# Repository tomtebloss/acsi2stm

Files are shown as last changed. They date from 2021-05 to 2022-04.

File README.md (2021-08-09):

**EXPERIMENTAL BRANCH - WORK IN PROGRESS**

Known issues on the integrated driver:
 * Mounting/overlay logic needs a full revamp.
 * Need to test the TOS loader correctly.

Known issues on the filesystem engine:
 * Fsfirst/Fsnext don't work well when creating/deleting files: Breaks recursive directory operations.
 * Pexec is not supported: you can't execute programs from the filesystem.
 * File descriptors are lost/reset when rescanning drives.
 * Filesystem access is very slow, code needs a lot of optimizations.

Known issues on the floppy emulator:
 * Low level access is not good. Formatting and low level copy doesn't work.
 * SD card hot swapping does not always work well.

Feature wish list:
 * RTC support (only needs a battery on the STM32).
 * Automatic drive desktop icon installation for TOS < 2.xx.
 * Dynamic floppy image mounting by hooking Pexec (and DESKTOP.INF auto patching).

ACSI2STM: Atari ST ACSI hard drive emulator
===========================================

This code provides a hard drive emulator for your Atari ST using an inexpensive STM32 microcontroller and a SD card.

The aim of this project is to be very easy to build, extremely cheap, reliable and safe for your precious vintage machine.

The module supports up to 5 SD card readers, showing them as 5 different ACSI devices plugged in. You can choose the ACSI
ID of each SD card by soldering CS wires on the matching STM32 pin.

It can work in 4 ways:
 * Expose a raw SD card as a hard disk to the Atari.
 * Expose a hard disk image file to the Atari.
 * Expose floppy disk images to the Atari with a built-in driver.
 * Expose a SD filesystem as a GEMDOS drive on the Atari.

Folders
-------

Here is how the project is organized:

 * acsi2stm: The arduino project.
 * doc: All the documentation about the project.
 * stmdrive: Sources for the floppy emulator and GEMDOS driver.
 * LICENSE: The license for the whole project.

Documentation
-------------

For a quick start guide on how to use an already built unit, check [HowToUse](doc/HowToUse.md).

For information about how to make the hardware, check [Hardware](doc/Hardware.md).

For information about compiling the firmware with Arduino and uploading it to the STM32, check [Compiling](doc/Compiling.md)

The doc folder contains more documentation, you may wish to browse it if needed.

Credits
-------

I would like to thanks the people that put invaluable information online that made this project possible in a finite amount of
time. Without them, this project would have not existed.

 * The http://atari.8bitchip.info website and his author, who also contributes on various forums.
 * The Hatari developpers. I used its source code as a reference for ACSI commands.
 * The emuTOS developpers. I used its source code for many tricks and lists.
 * The UltraSatan project for their documentation.
 * Sr Antonio, Edu Arana, Frederick321, Ulises74, Maciej G., Olivier Gossuin and Marcel Prisi for their very detailed feedback.
   that helped me a lot for fine tuning the DRQ/ACK signals and other various aspects of the projects.
 * All the kind people sharing their issues on GitHub. That really helps a lot making this project better.

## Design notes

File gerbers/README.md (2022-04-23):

<h1 align="center">
PCB for combining bluepill, microSD card reader and DB19 connector
</h1>

---

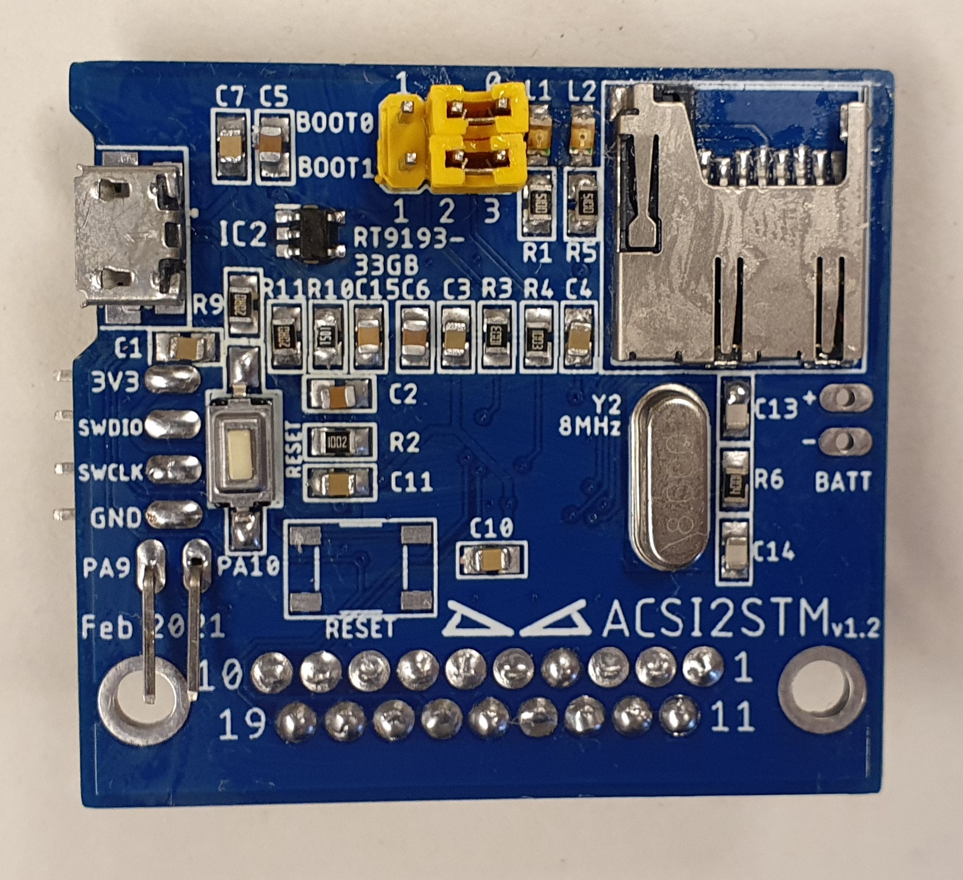
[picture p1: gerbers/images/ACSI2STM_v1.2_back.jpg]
Back side of soldered board
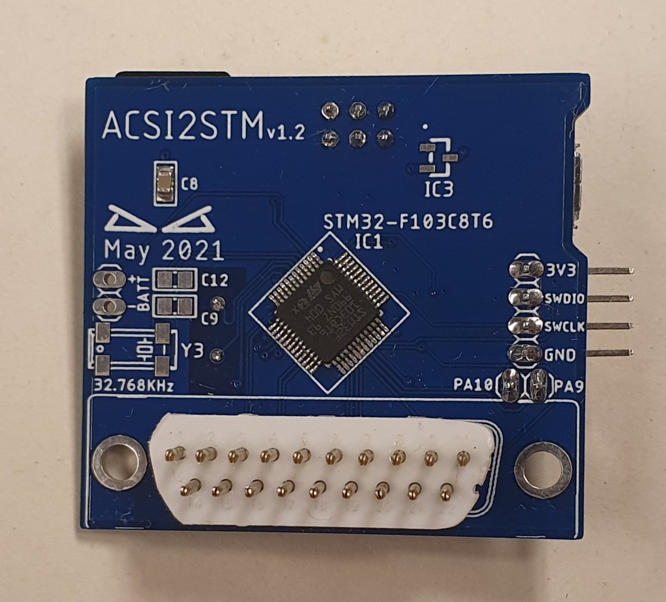
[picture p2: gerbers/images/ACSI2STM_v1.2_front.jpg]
Front side of soldered board


## History

This PCB was only made for me and the goal was to get a small PCB made with everything on it. A few people asked if I could make it public. So it is a "work in progress". There is no way to change ID at the moment, but I have plans to make a new PCB to change ID on the unit between 0-4. Right now the ID is fixed to ID0. There is also some components not needed for this project but was present on the bluepill. So download the zip with the gerbers and order your board from your favourite PCB manufactor. Based on the [bluepill schematics]. 

---

## "bluepill"

<h1 align="center">
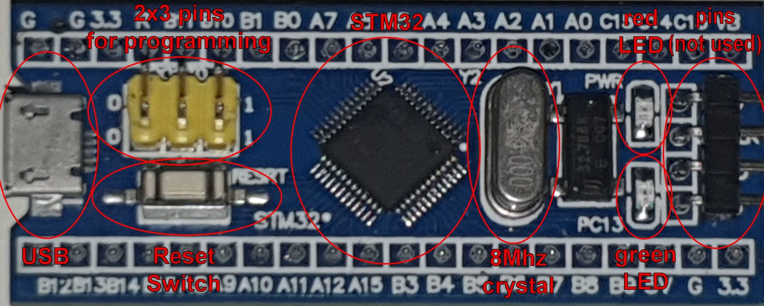
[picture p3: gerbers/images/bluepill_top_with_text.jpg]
Top side of bluepill PCB
 
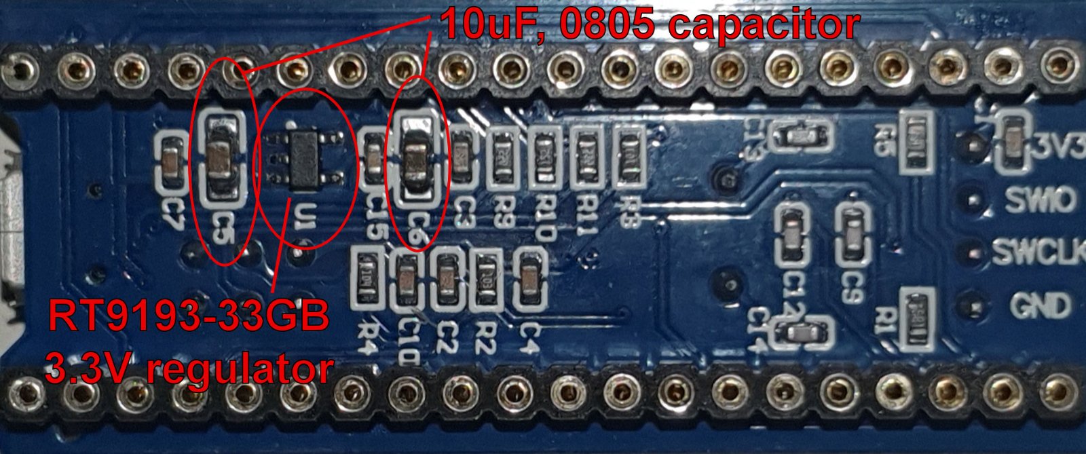
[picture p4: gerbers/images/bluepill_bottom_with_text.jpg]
Bottom side of bluepill PCB
 
</h1>
 
Some parts can be be used from the [bluepill] board. Most of the passive part on the bluepill is 0603 and although they could have been used on the new board, I opted to use 0805 for everything for easier soldering. They are cheap anyway. All components can however be order individually, you don't have to scavange parts from a bluepill. <strong>20220423: [R10 changed to 1.5K]. BOM updated.</strong>

  * USB connector can probably fit on the new board. But you have to cut of the small plastic pegs underneath. I used new connector on mine.
  * 8MHz crystal.
  * 2x3 pinheader (and associated jumper).
  * Red and yellow LED. I used new LED on mine (green for power (L1) and yellow for activity(L2)).
  * Right angle pins. Only used for programming. 
  * Reset switch. There is two different version depending on bluepill model. Only use one on the new board.
  * STM32.
  * LDO 5V to 3.3V regulator.
  * 10uF capacitors.

---

## Useful info

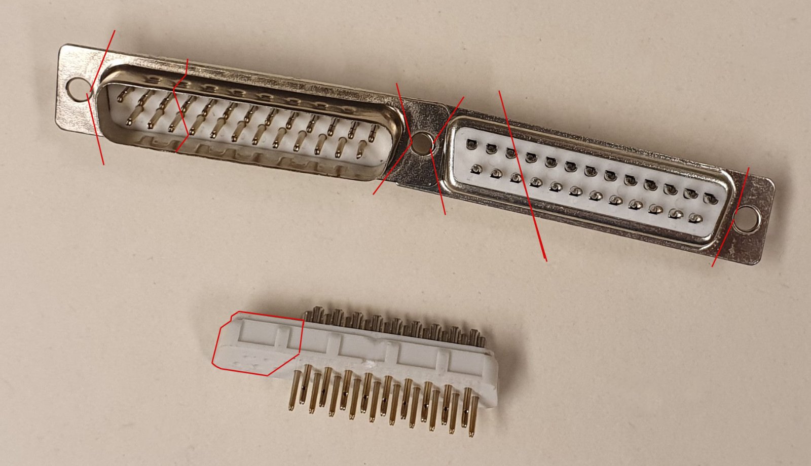
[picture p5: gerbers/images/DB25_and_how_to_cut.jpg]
Cut down a DB25
-  Use only one 3.3V LDO regulator. If you don't use the LDO from the bluepill there is a SOT-23 footprint on the other side (IC3) that can be used. 
- Battery connector, 32,768KHz crystal (Y3), capacitor is not used (C9 and C12).
- For programming the STM32 use the `3V3`, `GND`, `PA9` and `PA10` with a [FTDI programmer] (with 3V3 on VCC pin). Set `BOOT0` to 1 with the jumper. Reset switch is probably of use as well when programming. Download [STM32CubeProgrammer] and upload the v2.1 [binary] firmware to the STM32. <strong>20220103: I updated the [binary] to get it working better as discussed in [issue 16]. I used 18 MHz but also did a version with 8MHz.</strong>
- I made the PCB to use 19 pin D-SUB connector and solder it directly into the PCB. They can be pricy to get hold of so I made my own out of 25 pin D-SUB connector insted. The solder end don't go that far into the PCB so don't force it in and try to get it flush. There should be a gap.
- <strong>20220103: I could never get the unit to autoboot with HDDriver. But EmuTOS detected it and autobooted. Also P.Putniks HD driver autobooted. Tried in TOS v2.06, TOS v1.04 (with [IDE patch] from Christian Zietz) and EmuTOS v1.</strong>

---

## Speed test

I used [AHPT] by P.Putnik to test the units speed. Here you can download [AHPT94.ZIP] directly. <strong>Updated speed test 20220103.</strong>

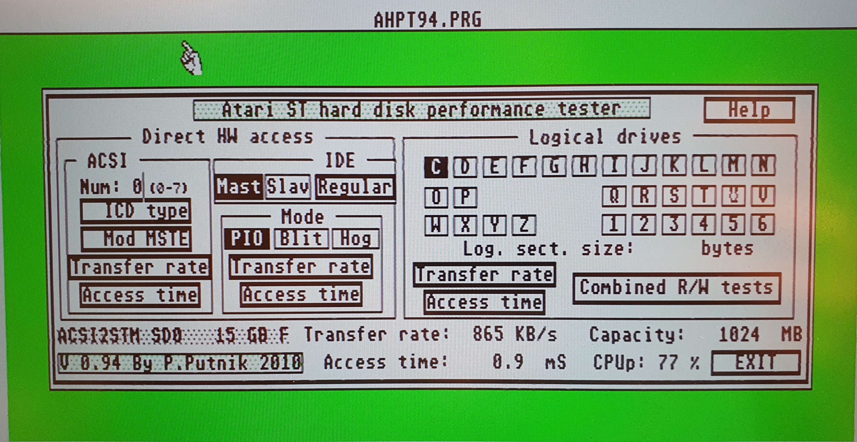
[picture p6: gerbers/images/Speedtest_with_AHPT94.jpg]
Speed test with AHPT94


---

Bill of material for this is listed in the <a href="https://github.com/tomtebloss/acsi2stm/blob/master/gerbers/ACSI2STM%20v1.2%20BOM.txt">`ACSI2STM vx.x BOM.txt`</a> 

PCB made by [DoG] in Eagle v9.6.2.

[bluepill]: https://stm32-base.org/boards/STM32F103C8T6-Blue-Pill.html
[FTDI programmer]: https://www.google.com/search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
[binary]: binary/acsi2stm.v2.1.18MHz.ino.generic_stm32f103c.bin
[STM32CubeProgrammer]: https://www.st.com/en/development-tools/stm32cubeprog.html
[AHPT]: https://atari.8bitchip.info/ahpt.html
[AHPT94.ZIP]: https://atari.8bitchip.info/AHPT9.ZIP
[DoG]: https://www.exxoshost.co.uk/forum/memberlist.php?mode=viewprofile&u=255
[issue 16]: https://github.com/retro16/acsi2stm/issues/16
[IDE patch]: https://github.com/czietz/ideboot
[bluepill schematics]: https://stm32-base.org/assets/pdf/boards/original-schematic-STM32F103C8T6-Blue_Pill.pdf
[R10 changed to 1.5K]: https://stm32-base.org/boards/STM32F103C8T6-Blue-Pill.html

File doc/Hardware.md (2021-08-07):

Building the hardware for ACSI2STM
==================================

Hardware needed
---------------

 * A STM32F103C8T6 or compatible board. You can find them for a few dollars online. The "blue pill" works out of the box
   and the "black pill" requires minor modifications.
 * One or more SD card port(s) for your STM32. You can also solder wires on a SD to microSD adapter.
 * One or more SD card(s).
 * A male DB19 port (you can modify a DB25 port to fit) with a ribbon cable.
 * (recommended) A protoboard PCB to solder all the components and wires together.
 * Do *NOT* connect USB data lines on the STM32. Use the +5V or +3.3V pin to power it if you are unsure.

Building the ACSI cable
-----------------------

ACSI pin numbers, looking at the male connector pins:

    ---------------------------------
    \ 01 02 03 04 05 06 07 08 09 10 /
     \ 11 12 13 14 15 16 17 18 19  /
       ---------------------------

Use this table to match pins on the ACSI port and the STM32:

| ACSI | STM32 | PIN | Description |
|:----:|:-----:|:---:|---|
|  01  | PB8 | D0  | Data 0 (LSB) |
|  02  | PB9 | D1  | Data 1 |
|  03  | PB10  | D2  | Data 2 |
|  04  | PB11  | D3  | Data 3 |
|  05  | PB12  | D4  | Data 4 |
|  06  | PB13  | D5  | Data 5 |
|  07  | PB14  | D6  | Data 6 |
|  08  | PB15  | D7  | Data 7 (MSB) |
|  09  | PB7 | CS  | Chip Select |
|  10  | PA8 | IRQ | Interrupt |
|  11  | GND | GND | Ground |
|  12  | (nc)  | RST | Reset |
|  13  | GND | GND | Ground |
|  14  | PA12  | ACK | Acknowledge |
|  15  | GND | GND | Ground |
|  16  | PB6 | A1  | Address bit |
|  17  | GND | GND | Ground |
|  18  | (nc)  | R/W | Read/Write |
|  19  | PA11  | DRQ | Data request |

**WARNING**: Pinout changed in v2.0: PA8 and PA12 are swapped.

Notes:

 * GND is soldered together on the ST side. You can use a single wire for ground.
 * Reset is not needed as the STM32 resets itself if it stays in an inconsistent state for more than 2 seconds.
 * Keep the wires short. I had strange behavior with cables longer than 10cm (4 inches).
 * The read/write pin is not needed.
 * You can build a DB19 out of a DB25 by cutting 6 pins on one side and part of the external shielding. Male DB25
   are easy to find because they were used for parallel port cables or serial port sockets.
 * You will have to power the STM32 separately (e.g. with a USB cable).

Connecting the SD cards
-----------------------

SD card pins

        ______________________
      /|  |  |  |  |  |  |  | |
     /_|01|02|03|04|05|06|07|8|
    |  |__|__|__|__|__|__|__|_|
    |09|                      |
    |__|                      |

Use this table to match pins on the SD card port and the STM32:

| SD  | STM32 | PIN |
|:---:|:-----:|:---:|
| 01  | PA4 * | CS  |
| 02  | PA7 | MOSI|
| 03  | GND | VSS |
| 04  | +3.3V | VDD |
| 05  | PA5 | CLK |
| 06  | GND | VSS |
| 07  | PA6 | MISO|
| 08  | (nc)  | RSV |
| 09  | (nc)  | RSV |

If you want to use multiple SD cards, connect all SD card pins to the same STM32 pins except CS (SD pin 1).

Here is the table that indicates the STM32 pin for each CS pin of the different SD cards:

| ACSI ID | STM32 | Connect to |
|---:|:---|---|
| 0 | PA4 | SD 0 pin 1 or GND |
| 1 | PA3 | SD 1 pin 1 or GND |
| 2 | PA2 | SD 2 pin 1 or GND |
| 3 | PA1 | SD 3 pin 1 or GND |
| 4 | PA0 | SD 4 pin 1 or GND |

Leave unused CS pins unconnected.

**WARNING**: Pinout changed in v2.0: PA0 was added, PBx were removed and unused SD card CS pins *must not* be grounded anymore.

For example, if you want 3 SD cards detected on ACSI IDs 0, 1 and 4:
 * Connect PA4 to pin 1 of the first SD card.
 * Connect PA3 to pin 1 of the second SD card.
 * Connect PA0 to pin 1 of the third SD card.
 * Leave PA1 and PA2 unconnected.

Notes:

 * The SD card had 2 GND pins. I don't know if they have to be both grounded, maybe one wire is enough.
 * You should put a decoupling capacitor of about 100nF between VDD and VSS, as close as possible from the SD card pins.
 * If you need other ACSI IDs, you can change the sdCs array in the source code. See "Compile-time options" below.
 * CS pins must be on GPIO port A (PA pins).

Using on a "Black pill" STM32 board
-----------------------------------

If you have these cheap "STM32 minimum development boards" from eBay, Amazon, Banggood or other chinese sellers, chances are that
you have either a "blue pill" or a "black pill" board. "blue" or "black" refers to the color of the PCB.

The problem with black pill designs is that the onboard LED is wired on PB12 instead of PC13, messing with data signals.

You will have to desolder the onboard LED (or its current-limiting resistor right under).

If you want an activity LED, put an external one with a 1k resistor in series on PC13.

Other boards were not tested and may require further adjustments.

Adapting a v1.0 board to v2.0
-----------------------------

If you built a board for v1.0, here are the changes you will have to do:

 * Cut the trace (or wire) between pin A8 of the STM32 and pin 14 of the ACSI port
 * Cut the trace (or wire) between pin A12 of the STM32 and pin 10 of the ACSI port
 * Solder a wire between pin A8 of the STM32 and pin 10 of the ACSI port
 * Solder a wire between pin A12 of the STM32 and pin 14 of the ACSI port
 * Cut any traces between A4, A3, A2, A1, B0, B1, B3 of the STM32 that go to GND. Make sure to keep traces that go to the SD card
   CS pin.

Sorry for the major inconvenience, but I had to do this to use hardware timers and the SdFat library that
use fixed pins on the microcontroller.

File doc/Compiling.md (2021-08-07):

Compiling and flashing the software for ACSI2STM
================================================

For a tutorial on how to build the hardware part, see the [Hardware](Hardware.md) page.

Hardware needed
---------------

 * A STM32 board.
 * A USB-serial dongle for programming the STM32 chip, with a 3.3V USART.
 * Do *NOT* connect USB data lines on the STM32. Use the +5V or +3.3V pin to power it if you are unsure.

You may use STLink, but I had no success using it, some other people did, your mileage may vary.

Software needed
---------------

 * The Arduino software with the Roger Clark Melbourne STM32 library.
 * The SdFat Arduino library by Bill Greiman.
 * A hard drive driver for your Atari ST:
   * AHDI should work but is not recommended.
   * ICD pro driver is tested.
   * Peter Putnik's driver is reported to work.

Installing software
-------------------

Install the [STM32 library](https://github.com/rogerclarkmelbourne/Arduino_STM32/wiki/Installation). The doc says that it only
works on Arduino 1.8.5 but that does seems to work with more recent versions too (confirmed working with Arduino 1.18.15).

In the Tools / Manage Libraries menu of the Arduino interface, search for "SdFat" and install "SdFat by Bill Greiman".

In the Tools menu of the Arduino interface, select the following:

 * Board: Generic STM32F103C series
 * Variant: STM32F103C8
 * Upload method: Serial
 * CPU speed: 72MHz (normal)
 * Optimize: Faster (-O2)
 * Port: your USB serial dongle

Note: you can use any setting in the "Optimize" menu. O2 is recommended for fastest performance, O3 does not bring any speed
improvement but generates much bigger code.

If you have different options in the Tools menu, it may be because you don't have the correct board installed.

Then, you will be able to upload the program to the STM32.

Programming the STM32
---------------------

Set the USB dongle to 3.3V if you have a jumper for that. Connect TX to PA10, RX to PA9 and the GND pins together.

On the STM32 itself, set the BOOT0 jumper to 1 to enable the serial flash bootloader. Reset the STM32 then click Upload.

Once the chip is programmed, switch the BOOT0 jumper back to 0.

Note: the debug output sends data at 115200bps. Set the serial monitor accordingly.

Compile-time options
--------------------

The file acsi2stm/acsi2stm.h contains a few #define that you can change. They are described in the source itself.

Settings that you might wish to change:

 * ACSI_DEBUG: Enables debug output on the serial port. Moderate performance penalty.
 * ACSI_VERBOSE: Requires ACSI_DEBUG. Logs all commands and low-level trafic on the serial port. High performance penalty.
 * IMAGE_FILE_NAME: The image file to use as a hard disk image on the SD card.
 * DRIVE_A_FILE_NAME: The image file to use as a floppy disk image. Same for drive B.
 * ACSI_BOOT_OVERLAY: Turn on or off the boot sector overlay to load the integrated driver.

If you need a reference debug output, see the debug_output.txt file. This contains a full trace of a standard ICD PRO setup booting.

Rebuilding the emudrive blob
----------------------------

To build the driver, you need [vasm](http://sun.hasenbraten.de/vasm/).

You need the _m68k_ CPU with the _mot_ syntax. Build it using the following command:

    make CPU=m68k SYNTAX=mot

Once compiled, put vasmm68k_mot anywhere in your PATH.

Generating the release zip package
----------------------------------

The build_relase.sh script is provided. It's a bash script for Linux, but if you use any other platform, you
can run the vasmm68k_mot and xxd commands by hand. If you have a script for other platforms, contributions are welcome.

Note: this script will modify acsi2stm.h to patch ACSI2STM_VERSION from the VERSION file.  It will also regenerate acsi2stm/boot.h with the new driver payload.

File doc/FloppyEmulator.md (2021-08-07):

ACSI2STM floppy emulator
========================

ACSI2STM supports mounting floppy images by hooking block device driver calls. While this is not bullet proof (it will fail for
programs that do direct hardware access) it's a nice convenience to mount *.st files easily.

This driver supports SD card hotplug and falls back to the hardware drive when no SD card is inserted or no image is found.

Floppy images can be up to 32M and must be formatted using FAT12.

How to use
----------

Format your SD card in FAT32 or EXFAT, create a folder named "acsi2stm" and put a floppy image file named "drive_a.st" in it.

You can also put an image named "drive_b.st" to emulate drive B. The driver is smart enough to enable or disable the popup that
asks to insert floppy B in drive A as required.

How not to use
--------------

If you have a hard drive driver that mounts the SD card containing floppy images don't touch the floppy image file while the floppy
drive is being accessed.

Low level tools such as disk formatters/copiers are unlikely to work. Some can be fixed by improving the driver, others cannot be
supported at all because they do direct hardware access.

Supported image formats
-----------------------

The driver only supports raw floppy images (a.k.a. *.st files). The file must be a multiple of 512 bytes or it won't load at all.

The driver will try to guess floppy geometry based on the file size when accessing the image using low level track/side/sector
addressing scheme.

What if I have more than 1 SD card with floppy images ?
-------------------------------------------------------

The driver will try to load images from devices in the reverse order: it tries the last SD card slot first, then goes back to the
first slot until it finds a suitable floppy image.

You can put drive A and drive B images on separate SD card readers.

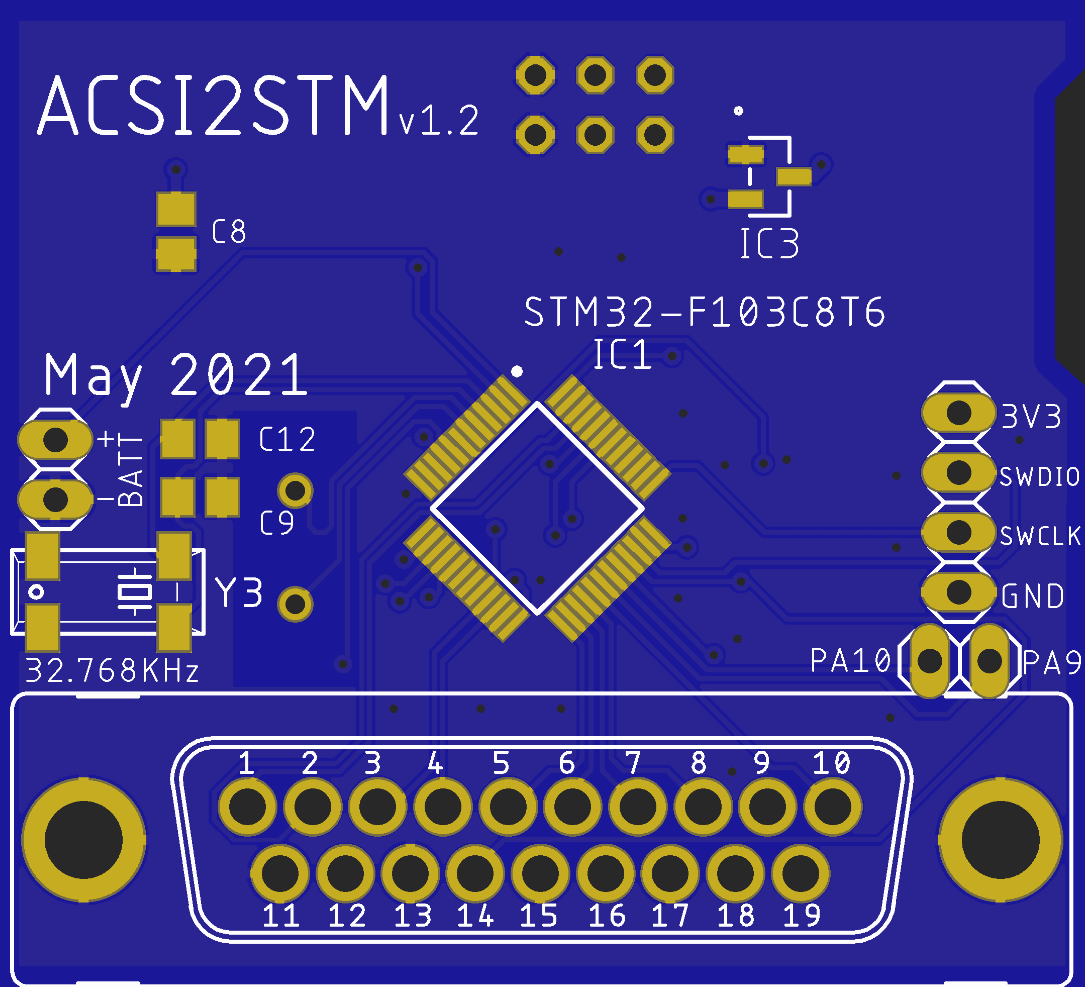
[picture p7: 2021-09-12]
gerbers/images/ACSI2STM_v1.2_PCB_top.gif

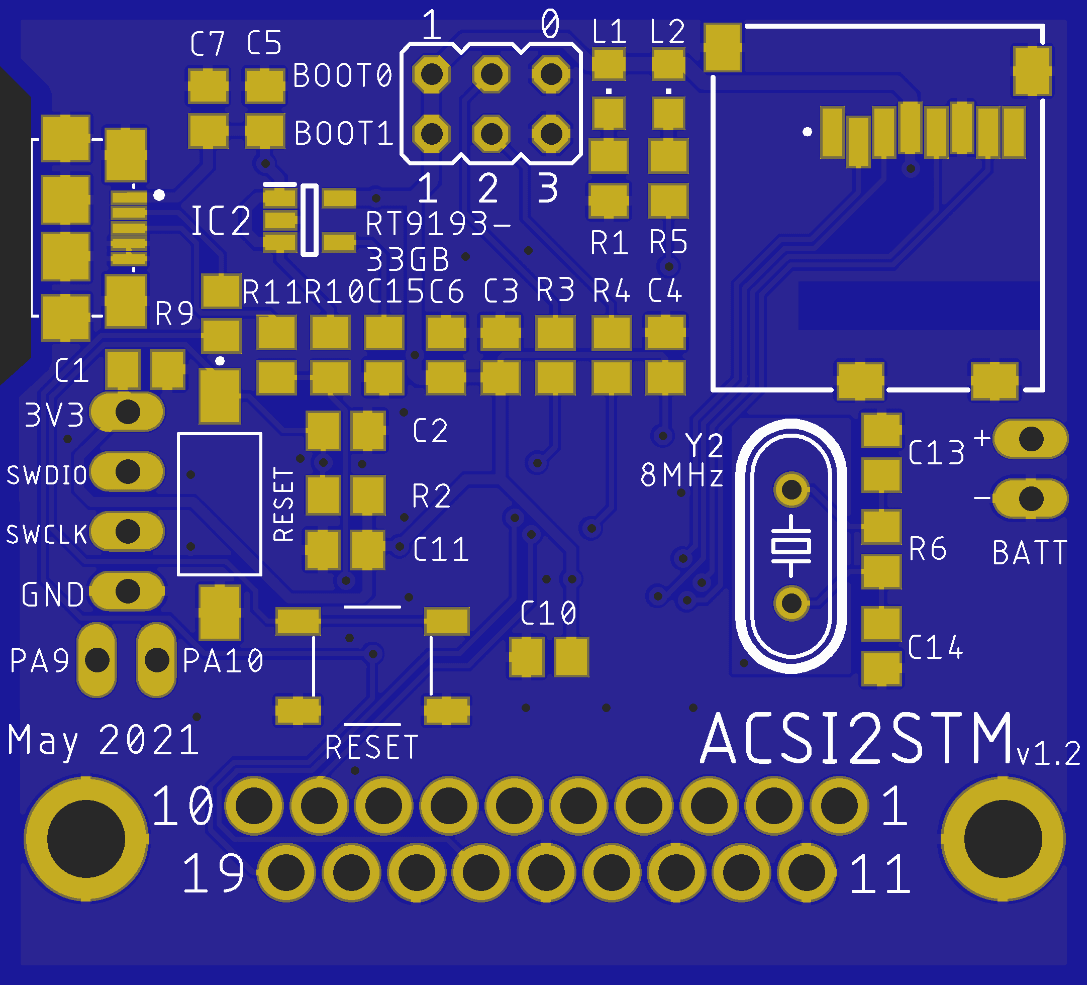
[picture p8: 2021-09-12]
gerbers/images/ACSI2STM_v1.2_PCB_bottom.gif

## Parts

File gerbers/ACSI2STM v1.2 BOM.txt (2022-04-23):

ACSI2STM v1.2 by DoG May 2021

Part    Value                    Device                   Package                      Description                                                                                                 AVAILABILITY BUILT_BY    CREATED_BY     DESCRIPTION                                                                                                 DIGI-KEY_PART_NUMBER DIGIKEY_PART_NUMBER DIGI_KEY_PART_NUMBER HEIGHT  MANUFACTURER                        MANUFACTURER_NAME  MANUFACTURER_PART_NUMBER MF                          MOUSER_PART_NUMBER MOUSER_PRICE-STOCK                                                                                         MP                  MPN             OC_FARNELL OC_NEWARK PACKAGE POPULARITY PRICE PURCHASE-URL                                                         SOURCELIBRARY        SPICEPREFIX VENDOR   
C1      0.1uF                    C-EUC0805                C0805                        CAPACITOR, European symbol                                                                                                                                                                                                                                                                                                                                                                                                                                                                                                                                                                                                                       88                                                                                                         C                    
C2      1uF                      C-EUC0805                C0805                        CAPACITOR, European symbol                                                                                                                                                                                                                                                                                                                                                                                                                                                                                                                                                                                                                       88                                                                                                         C                    
C3      0.1uF                    C-EUC0805                C0805                        CAPACITOR, European symbol                                                                                                                                                                                                                                                                                                                                                                                                                                                                                                                                                                                                                       88                                                                                                         C                    
C4      0.1uF                    C-EUC0805                C0805                        CAPACITOR, European symbol                                                                                                                                                                                                                                                                                                                                                                                                                                                                                                                                                                                                                       88                                                                                                         C                    
C5      10uF                     C-EUC0805                C0805                        CAPACITOR, European symbol                                                                                                                                                                                                                                                                                                                                                                                                                                                                                                                                                                                                                       88                                                                                                         C                    
C6      10uF                     C-EUC0805                C0805                        CAPACITOR, European symbol                                                                                                                                                                                                                                                                                                                                                                                                                                                                                                                                                                                                                       88                                                                                                         C                    
C7      0.1uF                    C-EUC0805                C0805                        CAPACITOR, European symbol                                                                                                                                                                                                                                                                                                                                                                                                                                                                                                                                                                                                                       88                                                                                                         C                    
C8      0.1uF                    C-EUC0805                C0805                        CAPACITOR, European symbol                                                                                                                                                                                                                                                                                                                                                                                                                                                                                                                                                                                                                       88                                                                                                         C                    
C9      20pF                     C-EUC0805                C0805                        CAPACITOR, European symbol (not used, for 32.768KHz crystal)                                                                                                                                                                                                                                                                                                                                                                                                                                                                                                                                                                                                                      88                                                                                                         C                    
C10     0.1uF                    C-EUC0805                C0805                        CAPACITOR, European symbol                                                                                                                                                                                                                                                                                                                                                                                                                                                                                                                                                                                                                       88                                                                                                         C                    
C11     0.1uF                    C-EUC0805                C0805                        CAPACITOR, European symbol                                                                                                                                                                                                                                                                                                                                                                                                                                                                                                                                                                                                                       88                                                                                                         C                    
C12     20pF                     C-EUC0805                C0805                        CAPACITOR, European symbol (not used, for 32.768KHz crystal)                                                                                                                                                                                                                                                                                                                                                                                                                                                                                                                                                                                                                      88                                                                                                         C                    
C13     20pF                     C-EUC0805                C0805                        CAPACITOR, European symbol                                                                                                                                                                                                                                                                                                                                                                                                                                                                                                                                                                                                                       88                                                                                                         C                    
C14     20pF                     C-EUC0805                C0805                        CAPACITOR, European symbol                                                                                                                                                                                                                                                                                                                                                                                                                                                                                                                                                                                                                       88                                                                                                         C                    
C15     22nF                     C-EUC0805                C0805                        CAPACITOR, European symbol                                                                                                                                                                                                                                                                                                                                                                                                                                                                                                                                                                                                                       88                                                                                                         C                    
IC1     STM32F103C8T6            STM32F103C8T6            QFP50P900X900X160-48N        Mainstream Performance line, ARM Cortex-M3 MCU with 64 Kbytes Flash, 72 MHz CPU, motor control, USB and CAN                                         Mainstream Performance line, ARM Cortex-M3 MCU with 64 Kbytes Flash, 72 MHz CPU, motor control, USB and CAN                                                               1.6mm                                       STMicroelectronics stm32f103c8t6                                        511-STM32F103C8T6  https://www.mouser.co.uk/ProductDetail/STMicroelectronics/STM32F103C8T6/?qs=bhCVus9SdFtq6kqxsU5%2FDA%3D%3D                                                                                                                                                                                                  
IC2     RT9193-33GB              RT9193-33GB              SOT94P279X130-5N             Low Dropout Regulators(LDO) Positive Fixed 300mV @ 300mA 5.5V 3.3V 300mA SOT-23-5 RoHS                                                              Low Dropout Regulators(LDO) Positive Fixed 300mV @ 300mA 5.5V 3.3V 300mA SOT-23-5 RoHS                                                                                    1.295mm                                     Richtek Tech       RT9193-33GB                                                                                                                                                                                                                                                                                                                                                                         
IC3     MCP1700T-3302E/TT        MCP1700T-3302E/TT        SOT-23_MC_MCH                (3.3V LDO. not used. If you don't use RT9193-33GB (can be found on blue pill) this can be used instead)                                             EMA_UL_Team                                                                                                                                                                                                                                                         MCP1700T-3302E/TT                                                                                                                                                                                                                                                                                                                         Microchip_2011-05-13             Microchip
J1      10118192-0001LF          10118192-0001LF          AMPHENOL_10118192-0001LF     Single Port 5 Contact Horizontal Right Angle Shielded Micro B USB 2.0 Connector                                                                     USB - micro B USB 2.0 Receptacle Connector 5 Position Surface Mount, Right Angle                           609-4613-1-ND                                                                                                                                         Amphenol ICC                                   https://www.digikey.se/product-detail/en/amphenol-icc-fci/10118192-0001LF/609-4613-1-ND/2785378            10118192-0001LF                                          None                     https://pricing.snapeda.com/search/part/10118192-0001LF/?ref=eda                                               
JP1                              JP3Q                     JP3Q                         JUMPER 3x2 pin                                                                                                                                                                                                                                                                                                                                                                                                                                                                                                                                                                                                                                           5                                                                                                                               
L1      RED                      LEDCHIPLED_0805          CHIPLED_0805                 LED (Any color can be used, I used green LED here)                                                                                                                                                                                                                                                                                                                                                                                                                                                                                                                                                                                                                                             52                                                                                                                              
L2      YELLOW                   LEDCHIPLED_0805          CHIPLED_0805                 LED (Any color can be used, I used yellow LED here)                                                                                                                                                                                                                                                                                                                                                                                                                                                                                                                                                                                                                                             52                                                                                                                              
MICROSD MEM2061-01-188-00-A_REVA MEM2061-01-188-00-A_REVA GCT_MEM2061-01-188-00-A_REVA Micro SD Memory Card Connector, 1.88mm Profile SMT,Push Push, with normally closed switch Check prices      Warning                                 10 (8 + 2) Position Card Connector microSD Surface Mount, Right Angle Gold                                                                                                                                                                                       Global Connector Technology                    https://www.digikey.se/product-detail/en/gct/MEM2061-01-188-00-A/2073-MEM2061-01-188-00-ACT-ND/9859683     MEM2061-01-188-00-A                                      None               None  https://pricing.snapeda.com/search/part/MEM2061-01-188-00-A/?ref=eda                                           
P1                               PINHD-1X2                1X02                         PIN HEADER for PA9 and PA 10 for programming                                                                                                                                                                                                                                                                                                                                                                                                                                                                                                                                                                                                                                       98                                                                                                                              
P2      SWD                      PINHD-1X4                1X04                         PIN HEADER (3V3 and GND used when programming)                                                                                                                                                                                                                                                                                                                                                                                                                                                                                                                                                                                                                                     91                                                                                                                              
P3                               PINHD-1X2                1X02                         PIN HEADER for battery connection (not used)                                                                                                                                                                                                                                                                                                                                                                                                                                                                                                                                                                                                                                      98                                                                                                                              
R1      510R                     R-EU_R0805               R0805                        RESISTOR, European symbol                                                                                                                                                                                                                                                                                                                                                                                                                                                                                                                                                                                                                        86                                                                                                         R                    
R2      10K                      R-EU_R0805               R0805                        RESISTOR, European symbol                                                                                                                                                                                                                                                                                                                                                                                                                                                                                                                                                                                                                        86                                                                                                         R                    
R3      100K                     R-EU_R0805               R0805                        RESISTOR, European symbol                                                                                                                                                                                                                                                                                                                                                                                                                                                                                                                                                                                                                        86                                                                                                         R                    
R4      100K                     R-EU_R0805               R0805                        RESISTOR, European symbol                                                                                                                                                                                                                                                                                                                                                                                                                                                                                                                                                                                                                        86                                                                                                         R                    
R5      510R                     R-EU_R0805               R0805                        RESISTOR, European symbol                                                                                                                                                                                                                                                                                                                                                                                                                                                                                                                                                                                                                        86                                                                                                         R                    
R6      1M                       R-EU_R0805               R0805                        RESISTOR, European symbol                                                                                                                                                                                                                                                                                                                                                                                                                                                                                                                                                                                                                        86                                                                                                         R                    
R9      20R                      R-EU_R0805               R0805                        RESISTOR, European symbol                                                                                                                                                                                                                                                                                                                                                                                                                                                                                                                                                                                                                        86                                                                                                         R                    
R10     1.5K                     R-EU_R0805               R0805                        RESISTOR, European symbol                                                                                                                                                                                                                                                                                                                                                                                                                                                                                                                                                                                                                        86                                                                                                         R
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

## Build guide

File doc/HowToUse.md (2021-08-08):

How to use ACSI2STM
===================

This quick start guide will explain how to use an aready working ACSI2STM unit.

Using a hard drive on the Atari requires a hard drive driver. The following drivers are known to work:

 * The integrated driver. Still experimental.
 * The original AHDI driver. This has a lot of limitations, you should avoid it.
 * The ICD PRO drivers. It formats hard drives to the Atari format.
 * The [Peter Putnik ACSI driver](https://atari.8bitchip.info/astams.php). It allows using standard FAT partitions.
   Disabling ACSI_DRIVER is recommended.

Using the integrated driver
---------------------------

 * Format a SD card with either FAT16, FAT32 or EXFAT. There is no size limit.
 * (optional) Make sure it's not bootable by the Atari: wipe its boot sector if necessary.
 * Insert the SD card into the reader.
 * Boot the ST, the ACSI2STM driver should load and your SD cards will appear as C:, D:, ... drives.

Notes:

 * This driver is highly experimental.
 * Running programs is still not supported.
 * If you have a hard drive driver that mounts FAT16 SD cards such as P. Putnik's, it may conflict with the GEMDOS driver. Wipe the
   boot sector to make sure to load the ACSI2STM driver.
 * You can use a SD card both as a GEMDOS drive and use floppy images at the same time. See [FloppyEmulator](FloppyEmulator.md)
 * You cannot mount a hard drive image as a GEMDOS drive. If your drive contains a hard drive image, filesystem will show the whole
   SD card while raw disk access will show the content of the image. This configuration is not recommended.

Creating a bootable hard drive with Peter Putnik's driver
---------------------------------------------------------

 * Download the ACSID07.ZIP file from [Peter Putnik drivers page](https://atari.8bitchip.info/astams.php).
 * Format a SD card with a single FAT16 partition.
 * Unzip to the root of that SD card.
 * Create a folder named AUTO and move BIGDOS.PRG in it.
 * If you prefer using a real floppy disk:
   * Copy AUBACD07.PRG from the zip file to the floppy.
 * Boot the Atari with the SD card inserted (and the floppy disk if you chose a real floppy disk).
 * On the GEM desktop, open drive A.
 * Run AUBACD07.PRG.
 * Press "I" to install the driver.

Creating a bootable hard drive with ICD PRO drivers
---------------------------------------------------

Download a floppy disk of ICD PRO drivers. They are available online as ST floppy images. Transfer it to a real floppy your ST can
read.

 * Run ICDFMT.PRG from the floppy.
   * Select the hard drive you wish to format in the list.
   * In the next screen, click "Verify passes" and set it to 0.
   * Click "Format", then "Continue".
   * The tool will create default partitions. The default settings are terrible: click "Clear" under "Size options".
   * Create your partitions by entering their size in the "Size" column. See below for partition size limitations.
   * Once you are happy, click "Partition entire disk".
   * Don't print the partition table: click "Cancel".
   * Exit to GEM by clicking "Quit".
 * Run HDUTIL.PRG.
   * Click "Boot" to make the disk bootable, select the "C" partition.
   * When prompted for ICDBOOT.PRG, accept the defaults and click OK.
 * (optional) in HDUTIL.PRG, click "Configure".
   * Click C:\ICDBOOT.SYS.
   * You can disable caching because ACSI2STM is so fast...
   * You can also disable unused device ids in "Skip ID(s)", it will improve boot time.
   * Click "Save" when you are finished.

Maximum partition sizes are the following:

 * 32MB (65532 sectors) for TOS 1.04 (ST and STF series)
 * 64MB for modern Linux kernels
 * 512MB (1048527 sectors) for TOS 1.62 and 2.06 (STE series)

Other TOS versions were not tested.

With different drivers, you may have different limits. This bridge supports 32 bits access for disks bigger than 8GB.

Working with image files
------------------------

Instead of using a raw SD card, you can use an image file instead.

Place a file named acsi2stm.img at the root of a standard SD card. The file must not be empty and must be a multiple of 512 bytes
to be detected as an image.

If the image file is in use, the ACSI unit name will contain IMG. In that case, the reported size is the size of the image, not
the size of the whole SD card.

The image is exposed as a raw device with no header. This is the same format as used in the Hatari emulator, making the image
directly compatible. You can also transfer data between a raw SD card and an image using tools like Win32 Disk Imager (for Windows)
or the dd command under Linux.

File system size limitations only apply on the Atari file system inside the image. The SD card itself can be of any size and it can
contain any amount of data other than the image itself.

The only downside to use images is performance. There will be a performance impact when using images because of the extra file
system layer.

Hard drive images can be combined with floppy images, even on the same SD card. See [FloppyEmulator](FloppyEmulator.md).

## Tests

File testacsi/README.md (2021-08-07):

ACSI2STM DMA transfer stress test
=================================

This program blasts DMA reads and writes non-stop with various data patterns. It checks that read data is identical to written
data.

In order to work, it uses the internal RAM buffer of the STM32, so it does *NOT* modify any data on SD cards.

To assemble, use vasm on PC or Devpac on Atari.

The program requires ACSI2STM compiled with the ACSI_DRIVER flag enabled.

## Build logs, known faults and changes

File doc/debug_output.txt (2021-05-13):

-----------------------
ACSI2STM SD bridge v2X1
-----------------------

Initializing the ACSI bridge ...
Reloading SD cards
ACSI device 0:ACSI2STM SD0 F16  30G /|\
    Has drive A
ACSI device 1:No SD card
ACSI device 2:No SD card
ACSI device 3:No SD card
ACSI device 4:No SD card
1 SD cards found

Waiting for the ACSI bus

--- Ready to go ---

[+8][<0][<0][<0][<1][<0]
Read dev=0 lun=0 block=0 count=1 mod=0
Reloading SD cards
Read SD0 block=0 count=1
Overlaying boot sector on device 0
DMA send (512 bytes): 48 E7 FF FE 41 FA 1 50 8F 10 EA F 41 FA 1 59 [...] OK
Success
[>0]
[+8][<E0][<0][<0][<3][<0]
Read dev=0 lun=7 block=0 count=3 mod=0
Read driver block=0 count=3
DMA send (512 bytes): 41 FA 3 BC 8F 10 2F 3C 0 0 4 4 48 7A FF F2 [...] OK
DMA send (512 bytes): 0 20 61 0 FE 94 4A 0 66 10 D8 BC 0 0 40 0 [...] OK
DMA send (512 bytes): 0 0 0 0 FE 94 4A 0 66 10 D8 BC 0 0 40 0 [...] OK
Success
[>0]
[+8][<F0][<0][<1][<1][<0]
Read dev=0 lun=7 block=1048577 count=1 mod=0
Read floppy info
Reloading SD cards
DMA send (512 bytes): 1 0 A3 82 13 E4 0 0 0 0 2 0 0 2 4 0 [...] OK
Success
[>0]
[+8][<A0][<0][<0][<1][<0]
Read dev=0 lun=5 block=0 count=1 mod=0
Reloading SD cards
Read SD0 block=0 count=1
DMA send (512 bytes): 60 1E FF FE 41 FA 1 50 8F 10 EA F 41 FA 1 59 [...] OK
Success
[>0]
[+8][<0][<0][<2][<8][<0]
Read dev=0 lun=0 block=2 count=8 mod=0
Read SD0 block=2 count=8
DMA send (512 bytes): 60 1A 0 0 0 DC 0 0 D 44 0 0 C 34 0 0 [...] OK
DMA send (512 bytes): 80 E 7 88 30 3C 0 8 48 40 80 6 5 88 61 0 [...] OK
DMA send (512 bytes): 50 1 86 C9 BE 2 FD 78 A0 AA 80 EA A2 AC 1 3A [...] OK
DMA send (512 bytes): 9 C7 61 0 F8 1A 4C DF 78 C0 80 D0 1 28 A0 AC [...] OK
DMA send (512 bytes): 66 2C 80 8 1 2 C0 E0 3 24 4A 28 E0 3C 1 1E [...] OK
DMA send (512 bytes): 40 0 1A 26 0 90 81 80 C6 80 66 14 C 13 7A 4 [...] OK
DMA send (512 bytes): 7C 20 3C 0 0 0 8A 80 E 1 56 80 E 1 6E 86 [...] OK
DMA send (512 bytes): E 99 1C 9F 38 9F 5A 97 7C 1 2 C3 33 2D 9C 28 [...] OK
Success
[>0]
[+12][<0][<0][<0][<38][<0]
DMA send (56 bytes): 0 80 1 0 1F 0 0 0 41 43 53 49 32 53 54 4D [...] OK
Success
[>0]
[+8][<1F][<FF][<FF][<1][<0]
Read dev=0 lun=0 block=2097151 count=1 mod=0
Read SD0 block=2097151 count=1
DMA send (512 bytes): 0 70 43 C1 80 0 C 1C 0 0 3 20 F1 5D 5B 30 [...] OK
Success
[>0]
[+8][<0][<0][<0][<1][<0]
Read dev=0 lun=0 block=0 count=1 mod=0
Reloading SD cards
Read SD0 block=0 count=1
Overlaying boot sector on device 0
DMA send (512 bytes): 48 E7 FF FE 41 FA 1 50 8F 10 EA F 41 FA 1 59 [...] OK
Success
[>0]
[+8][<0][<8][<0][<1][<0]
Read dev=0 lun=0 block=2048 count=1 mod=0
Read SD0 block=2048 count=1
DMA send (512 bytes): EB 3C 90 6D 6B 66 73 2E 66 61 74 0 2 10 10 0 [...] OK
Success
[>0]
[+28][<0][<0][<0][<1][<0]
Read dev=1 lun=0 block=0 count=1 mod=0
Reloading SD cards
Read SD1 block=0 count=1
Error 521
[>5]
[+28][<0][<0][<0][<1][<0]
Read dev=1 lun=0 block=0 count=1 mod=0
Reloading SD cards
Read SD1 block=0 count=1
Error 521
[>5]
[+48][<0][<0][<0][<1][<0]
Read dev=2 lun=0 block=0 count=1 mod=0
Reloading SD cards
Read SD2 block=0 count=1
Error 521
[>5]
[+48][<0][<0][<0][<1][<0]
Read dev=2 lun=0 block=0 count=1 mod=0
Reloading SD cards
Read SD2 block=0 count=1
Error 521
[>5]
[+68][<0][<0][<0][<1][<0]
Read dev=3 lun=0 block=0 count=1 mod=0
Reloading SD cards
Read SD3 block=0 count=1
Error 521
[>5]
[+68][<0][<0][<0][<1][<0]
Read dev=3 lun=0 block=0 count=1 mod=0
Reloading SD cards
Read SD3 block=0 count=1
Error 521
[>5]
[+88][<0][<0][<0][<1][<0]
Read dev=4 lun=0 block=0 count=1 mod=0
Reloading SD cards
Read SD4 block=0 count=1
Error 521
[>5]
[+88][<0][<0][<0][<1][<0]
Read dev=4 lun=0 block=0 count=1 mod=0
Reloading SD cards
Read SD4 block=0 count=1
Error 521
[>5]
[+8][<0][<A][<10][<1][<0]
Read dev=0 lun=0 block=2576 count=1 mod=0
Read SD0 block=2576 count=1
DMA send (512 bytes): 41 43 53 49 32 53 54 4D 20 20 20 10 0 0 58 85 [...] OK
Success
[>0]
[+8][<0][<F][<F0][<1][<0]
Read dev=0 lun=0 block=4080 count=1 mod=0
Read SD0 block=4080 count=1
DMA send (512 bytes): 2E 20 20 20 20 20 20 20 20 20 20 10 0 64 37 83 [...] OK
Success
[>0]
[+8][<0][<10][<0][<1][<0]
Read dev=0 lun=0 block=4096 count=1 mod=0
Read SD0 block=4096 count=1
DMA send (512 bytes): 60 1A 0 0 5E F4 0 0 8 6A 0 0 44 CE 0 0 [...] OK
Success
[>0]
[+8][<0][<10][<1][<F][<0]
Read dev=0 lun=0 block=4097 count=15 mod=0
Read SD0 block=4097 count=15
DMA send (512 bytes): 67 0 1 0 48 E7 7F E0 2F B 3F 0 2F E 21 4F [...] OK
DMA send (512 bytes): F ED 30 5 72 20 1C C1 51 C8 FF FC 26 4E 7E 0 [...] OK
DMA send (512 bytes): 72 E0 B2 80 66 14 70 28 3F 0 74 2 3F 2 72 3 [...] OK
DMA send (512 bytes): 0 20 42 40 41 EA 0 E5 4E BA 24 24 4A 80 66 1C [...] OK
DMA send (512 bytes): 65 10 B6 7C 0 10 65 0 1 74 B6 7C 0 13 62 0 [...] OK
DMA send (512 bytes): 0 1 0 6 66 16 70 3 D0 44 4E BA 4F 9C 20 6F [...] OK
DMA send (512 bytes): B2 70 20 0 63 1C 2 51 FF E0 6 51 0 21 30 11 [...] OK
DMA send (512 bytes): 60 5A 30 3 E5 48 20 72 0 0 22 8 67 4C 26 68 [...] OK
DMA send (512 bytes): 30 C2 72 2 D2 6A 0 E 74 0 34 1 D4 82 72 0 [...] OK
DMA send (512 bytes): 1 62 0 E 66 8 1C 3C 0 FD 60 0 0 7C C 6A [...] OK
DMA send (512 bytes): 0 6 3F 0 72 2 3F 1 74 3 3F 2 4E BA EB A [...] OK
DMA send (512 bytes): 10 28 0 19 E1 A9 D5 C1 60 AA 20 7 4C DF C F8 [...] OK
DMA send (512 bytes): 78 1 60 2 78 2 91 C8 B8 7C 0 2 66 4 70 1 [...] OK
DMA send (512 bytes): 0 F 0 2 60 6 3F 7C F0 0 0 2 3C 5 CC 6A [...] OK
DMA send (512 bytes): 7F 78 1A 93 60 4 1A AE 0 1 70 1 C0 43 67 6 [...] OK
Success
[>0]
[+8][<0][<9][<10][<1][<0]
Read dev=0 lun=0 block=2320 count=1 mod=0
Read SD0 block=2320 count=1
DMA send (512 bytes): F8 FF FF FF 63 0 FF FF 5 0 6 0 7 0 8 0 [...] OK
Success
[>0]
[+8][<0][<10][<10][<20][<0]
Read dev=0 lun=0 block=4112 count=32 mod=0
Read SD0 block=4112 count=32
DMA send (512 bytes): 9E 46 42 41 20 4A 30 5 4E BA FB 20 28 48 60 A8 [...] OK
DMA send (512 bytes): 0 10 DA 81 70 0 30 2F 0 E DE 80 4A 46 67 C [...] OK
DMA send (512 bytes): 20 A 67 40 20 4A 30 3 4E BA ED 22 2A 0 6A 2 [...] OK
DMA send (512 bytes): 0 14 28 15 70 FF B0 84 66 2 78 0 20 4 20 4E [...] OK
DMA send (512 bytes): FF FF 20 4B 4F EF 0 14 4C DF 2C 18 4E 75 48 E7 [...] OK
DMA send (512 bytes): 0 1C 43 D7 20 6A 0 14 4E BA 10 5C 3F 3 4E BA [...] OK
DMA send (512 bytes): 26 28 0 1C 20 3 24 68 0 18 20 4A 4E BA 11 9E [...] OK
DMA send (512 bytes): 70 CF 60 12 22 4A 20 4C 4E BA FB 30 33 FC 0 1 [...] OK
DMA send (512 bytes): C0 2C 0 B 67 6 36 BC 41 FF 60 10 70 8 C0 2C [...] OK
DMA send (512 bytes): 60 0 1 42 20 3C 42 44 4F 53 60 0 1 38 20 3C [...] OK
DMA send (512 bytes): 4E BA 9 AA 93 C9 70 1 20 6A 0 18 4E BA 0 88 [...] OK
DMA send (512 bytes): 32 28 0 6 43 F9 0 0 AC C 10 31 10 0 20 53 [...] OK
DMA send (512 bytes): BA 7C 2 0 6D EC 22 78 4 C6 43 E9 0 2B 41 EF [...] OK
DMA send (512 bytes): 20 8 66 E0 70 0 58 4F 26 5F 24 5F 4E 75 2F A [...] OK
DMA send (512 bytes): 0 90 3F 3 2F 2F 0 48 4E BA 6 7E 5C 4F 2A 0 [...] OK
DMA send (512 bytes): 2A 3 14 2B 0 1D E4 A5 32 2A 0 24 67 1A B6 AA [...] OK
DMA send (512 bytes): 30 4 E5 48 D0 44 D0 40 22 30 0 C4 6A 6 15 81 [...] OK
DMA send (512 bytes): 4E 75 52 40 41 E8 0 A B0 7C 0 5E 6D EC 70 FF [...] OK
DMA send (512 bytes): 0 DE B8 3C 0 5D 67 0 0 D6 B8 3C 0 7C 67 0 [...] OK
DMA send (512 bytes): 67 18 B0 3C 0 2A 67 12 B0 3C 0 5C 67 C B0 3C [...] OK
DMA send (512 bytes): 3F 1 4E BA F8 28 54 4F 52 43 B6 7C 0 5E 6D DE [...] OK
DMA send (512 bytes): 66 2 54 4D 24 4D 60 C C 12 0 5C 66 4 4B EA [...] OK
DMA send (512 bytes): 66 F2 42 1D 28 4B 4A 44 67 6 B8 7C 0 3 66 32 [...] OK
DMA send (512 bytes): 2A 0 20 4D 60 1E 42 43 16 18 67 62 B6 7C 0 1 [...] OK
DMA send (512 bytes): 66 F0 70 D8 60 5A 52 83 C6 BC FF FF FF FE B6 AA [...] OK
DMA send (512 bytes): FF FE 4A 83 6F 3A 4E BA 4 2 26 48 20 B 66 4 [...] OK
DMA send (512 bytes): 64 32 4E BA 0 56 26 38 4 BA D6 BC 0 0 3 20 [...] OK
DMA send (512 bytes): 0 0 77 68 4C DF 1C 0 4E 75 48 E7 0 38 91 C8 [...] OK
DMA send (512 bytes): 20 9 66 C0 4E BA FC 46 24 5F 4E 75 3F 3 36 0 [...] OK
DMA send (512 bytes): 3F 4 36 0 38 1 42 41 4E BA FE B4 3F 4 3F 3 [...] OK
DMA send (512 bytes): FF 2C 36 1F 4E 75 20 79 0 0 AB EE 22 50 10 29 [...] OK
DMA send (512 bytes): 32 4 30 3 4E BA FE A6 42 46 60 40 72 23 30 3 [...] OK
Success
[>0]
[+8][<0][<10][<30][<3][<0]
Read dev=0 lun=0 block=4144 count=3 mod=0
Read SD0 block=4144 count=3
DMA send (512 bytes): 4 B0 0 0 0 0 4 B0 0 0 0 0 4 B0 0 0 [...] OK
DMA send (512 bytes): 20 2F 20 49 53 4F 20 39 32 39 33 3A 31 39 38 37 [...] OK
DMA send (512 bytes): 7B 7C 7D 7E 80 8E 8F 90 92 99 9A 9B 9C 9D A5 A6 [...] OK
Success
[>0]
[+8][<0][<10][<33][<1][<0]
Read dev=0 lun=0 block=4147 count=1 mod=0
Read SD0 block=4147 count=1
DMA send (512 bytes): 6D 61 6C 6C 3A D A 0 3 20 0 0 0 0 0 0 [...] OK
Success
[>0]
[+8][<0][<10][<34][<1][<0]
Read dev=0 lun=0 block=4148 count=1 mod=0
Read SD0 block=4148 count=1
DMA send (512 bytes): 18 1 1 9A AC 7C 1 16 7E 28 6 8 90 6 38 14 [...] OK
Success
[>0]
[+8][<0][<9][<10][<1][<0]
Read dev=0 lun=0 block=2320 count=1 mod=0
Read SD0 block=2320 count=1
DMA send (512 bytes): F8 FF FF FF 63 0 FF FF 5 0 6 0 7 0 8 0 [...] OK
Success
[>0]
[+8][<0][<8][<0][<1][<0]
Read dev=0 lun=0 block=2048 count=1 mod=0
Read SD0 block=2048 count=1
DMA send (512 bytes): EB 3C 90 6D 6B 66 73 2E 66 61 74 0 2 10 10 0 [...] OK
Success
[>0]
[+8][<0][<A][<10][<1][<0]
Read dev=0 lun=0 block=2576 count=1 mod=0
Read SD0 block=2576 count=1
DMA send (512 bytes): 41 43 53 49 32 53 54 4D 20 20 20 10 0 0 58 85 [...] OK
Success
[>0]
[+8][<0][<F][<F0][<1][<0]
Read dev=0 lun=0 block=4080 count=1 mod=0
Read SD0 block=4080 count=1
DMA send (512 bytes): 2E 20 20 20 20 20 20 20 20 20 20 10 0 64 37 83 [...] OK
Success
[>0]

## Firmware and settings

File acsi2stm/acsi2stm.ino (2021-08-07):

/* ACSI2STM Atari hard drive emulator
 * Copyright (C) 2019-2021 by Jean-Matthieu Coulon
 *
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
 * You should have received a copy of the GNU General Public License
 * along with the program.  If not, see <http://www.gnu.org/licenses/>.
 */

// Requires the SdFat library by Bill Greiman

// Edit acsi2stm.h to change global values
#include "acsi2stm.h"

// Includes
#include "Debug.h"
#include "DmaPort.h"
#include "Acsi.h"
#include "RootDevice.h"

static_assert(sizeof(sdId) == sizeof(sdCs), "SD card CS pins and device id must match. Check sdCs and sdId arrays");

// Globals

DmaPort dma;
RootDevice roots[maxSd];
Acsi acsi;

// Main setup function
void setup() {
  ACSI_SERIAL.begin(ACSI_SERIAL_BAUD);
  while(!ACSI_SERIAL);

  // Send a few characters to synchronize autoconfigured USB-serial dongles.
  acsiDbgln("");
  delay(50);
  acsiDbgln("");
  delay(100);

  ACSI_SERIAL.println("-----------------------");
  ACSI_SERIAL.println("ACSI2STM SD bridge v" ACSI2STM_VERSION);
  ACSI_SERIAL.println("-----------------------");
  ACSI_SERIAL.println("");

  // Initialize the ACSI port
  dma.begin();

  // Map block devices to device id
  for(int i = 0; i < maxSd; ++i) {
    roots[i].begin(i + 1, sdId[i], sdCs[i], maxSd == 1);
    dma.addDevice(sdId[i]);
  }

  // Start the whole ACSI bridge engine
  ACSI_SERIAL.println("Initializing the ACSI bridge...");
  acsi.begin(&dma, roots, maxSd);

  ACSI_SERIAL.println("");
  ACSI_SERIAL.println("Detected volumes:");
  acsi.readDeviceDescription(dma.dataBuf);
  ACSI_SERIAL.flush();
  ACSI_SERIAL.println((char *)dma.dataBuf);

  ACSI_SERIAL.println("Waiting for the DMA bus to be ready...");
  ACSI_SERIAL.flush();

  dma.waitBusReady();

  ACSI_SERIAL.println("");
  ACSI_SERIAL.println("--- Ready to go ---");
  ACSI_SERIAL.println("");
  ACSI_SERIAL.flush();
}

// Main loop
void loop() {
  acsi.processCommand();
  return;
}

// vim: ts=2 sw=2 sts=2 et

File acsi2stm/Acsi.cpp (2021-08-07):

/* ACSI2STM Atari hard drive emulator
 * Copyright (C) 2019-2021 by Jean-Matthieu Coulon
 *
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
 * You should have received a copy of the GNU General Public License
 * along with the program.  If not, see <http://www.gnu.org/licenses/>.
 */

#include "Acsi.h"
#include "Debug.h"
#include "BlockDev.h"
#include "RootDevice.h"
#include <libmaple/iwdg.h>

#if ACSI_DRIVER && ACSI_BOOT_OVERLAY
const // xxd does not generate const arrays !
#include "boot.h"
#endif

void Acsi::begin(DmaPort *dma_, RootDevice *roots_, int rootCount_) {
  dma = dma_;
  roots = roots_;
  rootCount = rootCount_;
#if ACSI_DRIVER && ACSI_BOOT_OVERLAY
  bootOverlay = -1;
#endif
  reload();
}

void Acsi::processCommand() {
  uint8_t cmdBuf[11];

  // Wait for a command
  uint8_t cmd = dma->waitCommand();

  // Parse device id
  deviceId = cmd >> 5;

  // Remove device id from the command
  cmd &= 0x1f;

  // Compute command length
  int cmdLen = cmd == 0x1f ? 11 : 6;
  dma->readIrq(&cmdBuf[1], cmdLen - 1);

  acsiVerboseln("");

  // Set main device
  dev = devices[deviceId];

  // Parse LUN and remove it from cmdBuf
  if(cmd == 0x1f) {
    lun = cmdBuf[2] >> 5;
    cmdBuf[2] &= 0x1f;
  } else {
    lun = cmdBuf[1] >> 5;
    cmdBuf[1] &= 0x1f;
  }

#if ACSI_DRIVER
  // Parse drive
  driveId = -1;
  if(cmd == 0x1f) {
    if(cmdBuf[10] < maxDrives)
      driveId = cmdBuf[10];
  } else {
    if(cmdBuf[5] < maxDrives)
      driveId = cmdBuf[5];
  }

  drv = nullptr;
  if(driveId != -1 && drives[driveId])
    drv = &drives[driveId];

  curFs = nullptr;
  if(driveId >= 2 && driveId - 2 < maxFs)
    curFs = &fs[driveId - 2];
#endif

  Status status = AST_OK;

  // Execute the command
  switch(cmd) {
  default: // Unknown command
    acsiDbgln("Unknown command");
    if(dev)
      dev->lastSeek = false;
    status = AST_OPCODE;
    break;
  case 0x00: // Sense
  case 0x0d: // Correction
  case 0x15: // Mode select
  case 0x1B: // Ship
    // Always succeed
    if(dev)
      dev->lastSeek = false;
    break;
  case 0x04: // Format drive
  case 0x05: // Verify track
  case 0x06: // Format track
    if(dev)
      dev->lastSeek = false;
    // fall through case
  case 0x03: // Request Sense
    for(int b = 0; b < cmdBuf[4]; ++b)
      dma->dataBuf[b] = 0;

    if(cmdBuf[4] <= 4) {
      dma->dataBuf[0] = dev ? dev->lastErr & 0xff : (int)AST_NOMEDIUM & 0xff;
      if(dev && dev->lastSeek) {
        dma->dataBuf[0] |= 0x80;
        dma->dataBuf[1] = (dev->lastBlock >> 16) & 0xff;
        dma->dataBuf[2] = (dev->lastBlock >> 8) & 0xff;
        dma->dataBuf[3] = (dev->lastBlock) & 0xff;
      }
    } else {
      // Build long response in dma->dataBuf
      dma->dataBuf[0] = 0x70;
      if(dev) {
        if(dev->lastSeek) {
          dma->dataBuf[0] |= 0x80;
          dma->dataBuf[4] = (dev->lastBlock >> 16) & 0xff;
          dma->dataBuf[5] = (dev->lastBlock >> 8) & 0xff;
          dma->dataBuf[6] = (dev->lastBlock) & 0xff;
        }
        dma->dataBuf[2] = (dev->lastErr >> 8) & 0xff;
        dma->dataBuf[7] = 14;
        dma->dataBuf[12] = (dev->lastErr) & 0xff;
        dma->dataBuf[19] = (dev->lastBlock >> 16) & 0xff;
        dma->dataBuf[20] = (dev->lastBlock >> 8) & 0xff;
        dma->dataBuf[21] = (dev->lastBlock) & 0xff;
      } else {
        dma->dataBuf[2] = ((int)AST_NOMEDIUM >> 8) & 0xff;
        dma->dataBuf[7] = 14;
        dma->dataBuf[12] = ((int)AST_NOMEDIUM) & 0xff;
      }
    }
    // Send the response
    dma->send(cmdBuf[4]);
    
    break;
  case 0x08: // Read block
    block = (((int)cmdBuf[1]) << 16) | (((int)cmdBuf[2]) << 8) | (cmdBuf[3]);
    count = cmdBuf[4];
    control = cmdBuf[5];
    if(dev)
      dev->lastSeek = true;
    status = processRead();
    break;
  case 0x0a: // Write block
    block = (((int)cmdBuf[1]) << 16) | (((int)cmdBuf[2]) << 8) | (cmdBuf[3]);
    count = cmdBuf[4];
    control = cmdBuf[5];
    if(dev)
      dev->lastSeek = true;
    status = processWrite();
    break;
  case 0x0b: // Seek
    block = (((int)cmdBuf[1]) << 16) | (((int)cmdBuf[2]) << 8) | (cmdBuf[3]);
    count = 0;
    control = cmdBuf[5];
    if(dev)
      dev->lastSeek = true;
    status = processRead();
    break;
  case 0x12: // Inquiry
    if(!dev) {
      status = AST_NOMEDIUM;
      break;
    }
    // Fill the response with zero bytes
    for(uint8_t b = 0; b < cmdBuf[4]; ++b)
      dma->dataBuf[b] = 0;

    if(lun > 0)
      dma->dataBuf[0] = 0x7F; // Unsupported LUN
    dma->dataBuf[1] = 0x80; // Removable flag
    dma->dataBuf[2] = 1; // ACSI version
    dma->dataBuf[4] = 31; // Data length
    
    // Build the product string with the SD card size
    dev->root->getDeviceString((char *)dma->dataBuf + 8);
   
    dma->send(cmdBuf[4]);

    dev->lastSeek = false;
    break;
  case 0x1a: // Mode sense
    if(!dev) {
      status = AST_NOMEDIUM;
      break;
    }
    switch(cmdBuf[2]) { // Sub-command
    case 0x00:
      for(uint8_t b = 0; b < 16; ++b) {
        dma->dataBuf[b] = 0;
      }
      // Values got from the Hatari emulator
      dma->dataBuf[1] = 14;
      dma->dataBuf[3] = 8;
      // Send the number of blocks of the SD card
      dma->dataBuf[5] = (dev->blocks >> 16) & 0xff;
      dma->dataBuf[6] = (dev->blocks >> 8) & 0xff;
      dma->dataBuf[7] = (dev->blocks) & 0xff;
      // Sector size middle byte
      dma->dataBuf[10] = 2;
      dma->send(16);
      break;
    case 0x04:
      for(uint8_t b = 0; b < 24; ++b) {
        dma->dataBuf[b] = 0;
      }
      // Values got from the Hatari emulator
      dma->dataBuf[0] = 4;
      dma->dataBuf[1] = 22;
      // Send the number of blocks in CHS format
      dma->dataBuf[2] = (dev->blocks >> 23) & 0xff;
      dma->dataBuf[3] = (dev->blocks >> 15) & 0xff;
      dma->dataBuf[4] = (dev->blocks >> 7) & 0xff;
      // Hardcode 128 heads
      dma->dataBuf[5] = 128;
      dma->send(24);
      break;
    default:
      status = AST_INVARG;
      break;
    }
    break;
  case 0x1f: // ICD extended command
    switch(cmdBuf[1]) { // Sub-command
    case 0x25: // Read capacity
      if(!dev) {
        status = AST_NOMEDIUM;
        break;
      }

      // Send the number of blocks of the SD card
      dma->dataBuf[0] = (dev->blocks >> 24) & 0xff;
      dma->dataBuf[1] = (dev->blocks >> 16) & 0xff;
      dma->dataBuf[2] = (dev->blocks >> 8) & 0xff;
      dma->dataBuf[3] = (dev->blocks) & 0xff;

      // Send the block size (which is always 512)
      dma->dataBuf[4] = 0x00;
      dma->dataBuf[5] = 0x00;
      dma->dataBuf[6] = 0x02;
      dma->dataBuf[7] = 0x00;
      
      dma->send(8);

      break;
    case 0x28: // Read blocks
      // Compute the block number
      block = (((int)cmdBuf[3]) << 24) | (((int)cmdBuf[4]) << 16) | (((int)cmdBuf[5]) << 8) | (cmdBuf[6]);
      count = (((int)cmdBuf[8]) << 8) | (cmdBuf[9]);
      control = cmdBuf[10];
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

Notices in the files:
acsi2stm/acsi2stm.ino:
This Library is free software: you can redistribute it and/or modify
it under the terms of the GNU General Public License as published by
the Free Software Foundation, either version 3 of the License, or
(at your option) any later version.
